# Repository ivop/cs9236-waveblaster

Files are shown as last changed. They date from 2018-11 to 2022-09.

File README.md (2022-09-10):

# cs9236-waveblaster

A shrunken version of this design has been sold as the CrystalBlaster C1 IVO edition :)
https://www.serdashop.com/CrystalBlasterC1

Now there's a shrunken SMD version called the CrystalBlaster C2
https://www.serdashop.com/CrystalBlaster-C2

Note that I am not in any way affiliated with the seller. My design is open source and the functionality has not changed. You can build it yourself or buy it :)

https://www.youtube.com/watch?v=O6CxHOC51vI

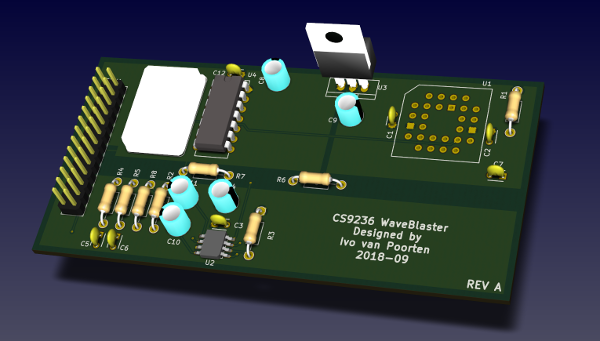
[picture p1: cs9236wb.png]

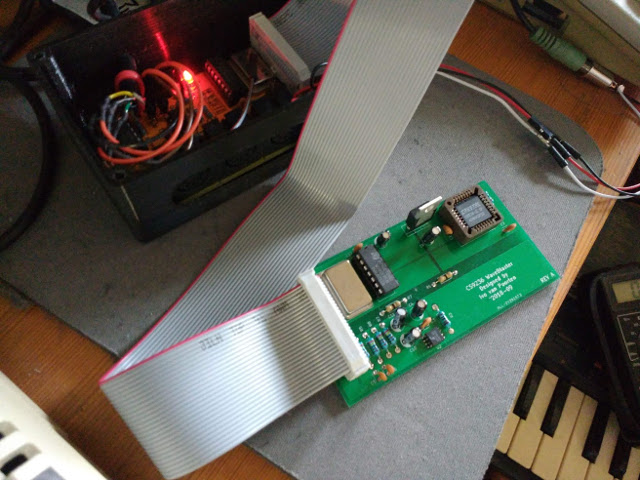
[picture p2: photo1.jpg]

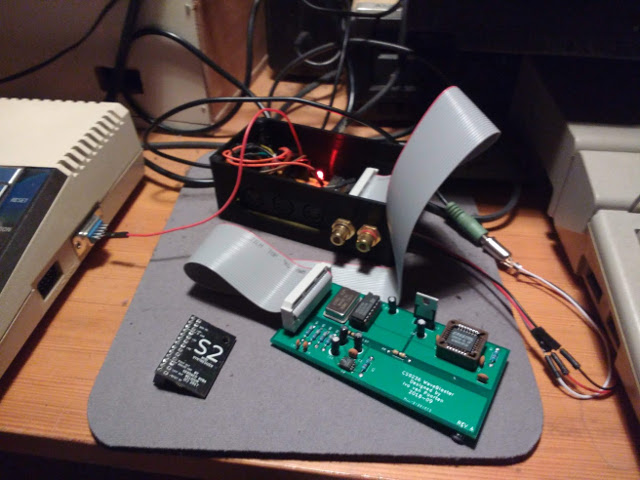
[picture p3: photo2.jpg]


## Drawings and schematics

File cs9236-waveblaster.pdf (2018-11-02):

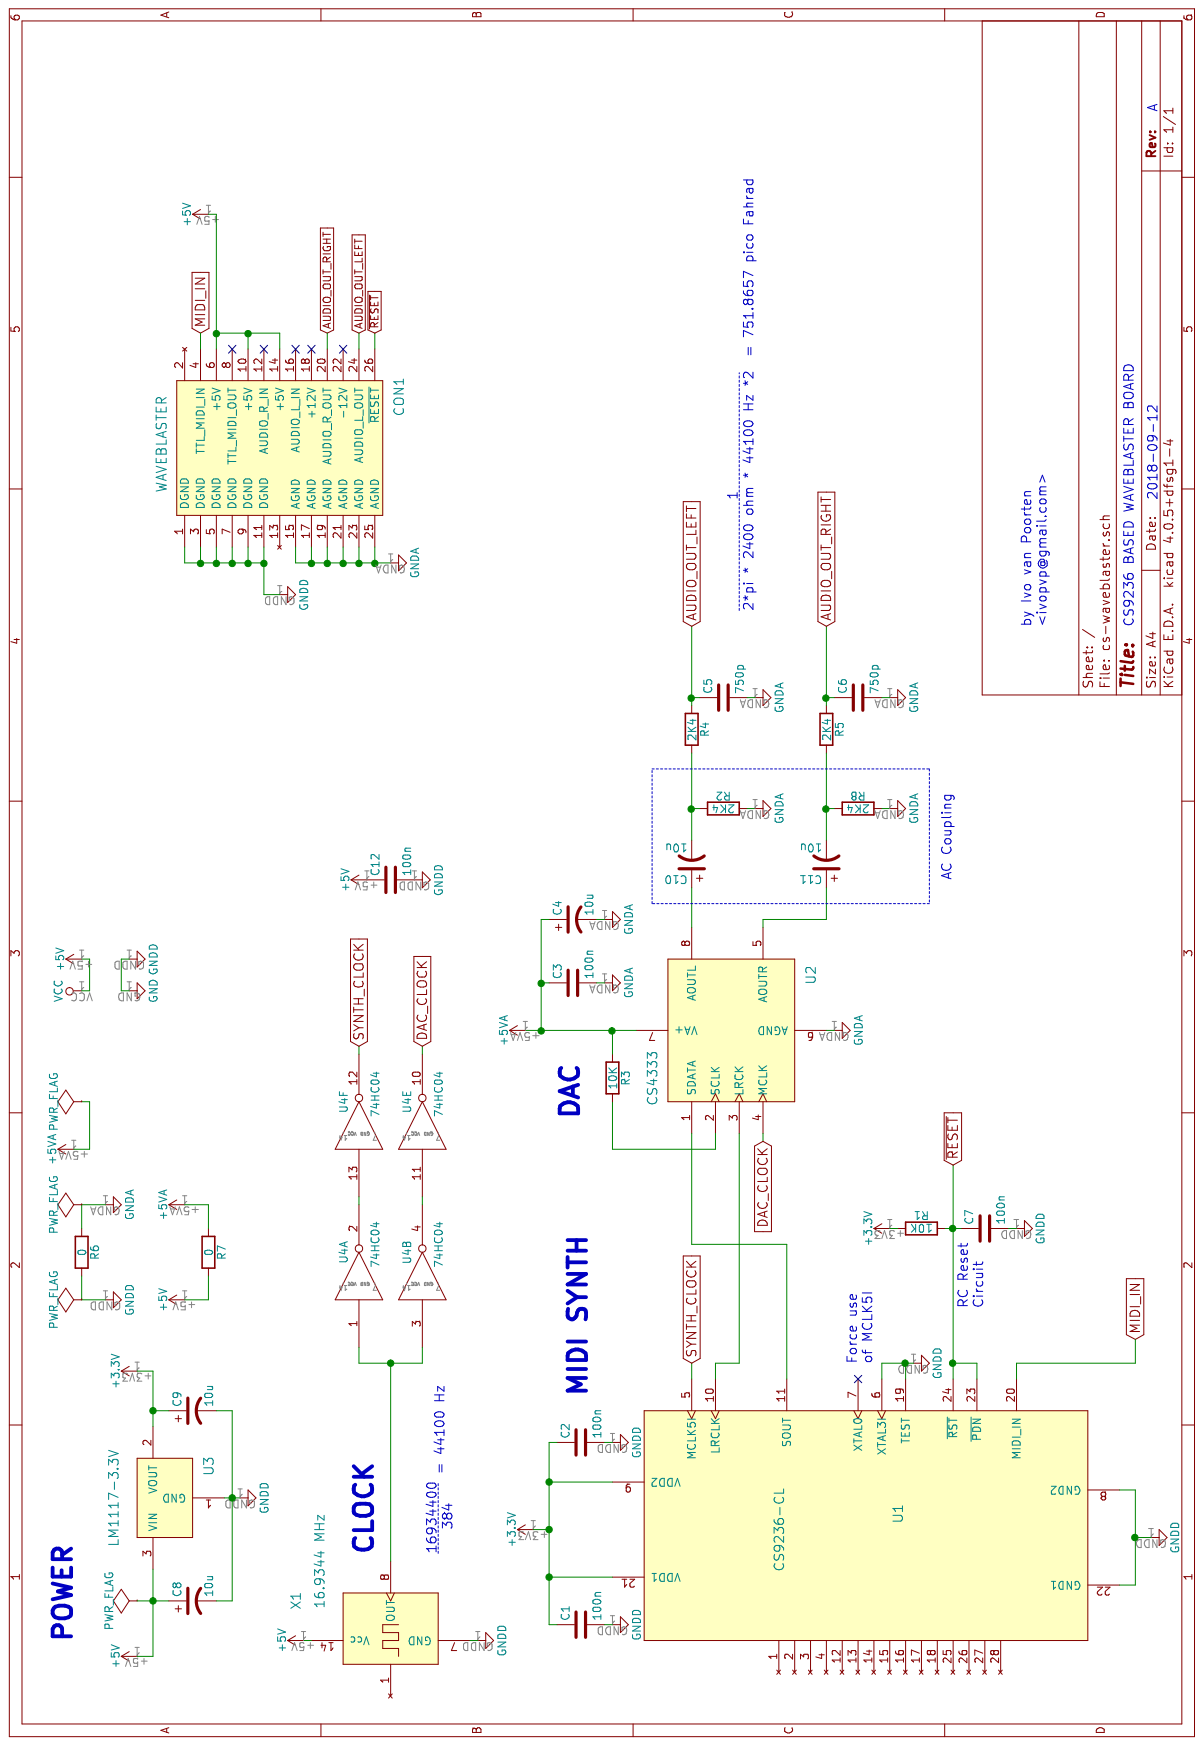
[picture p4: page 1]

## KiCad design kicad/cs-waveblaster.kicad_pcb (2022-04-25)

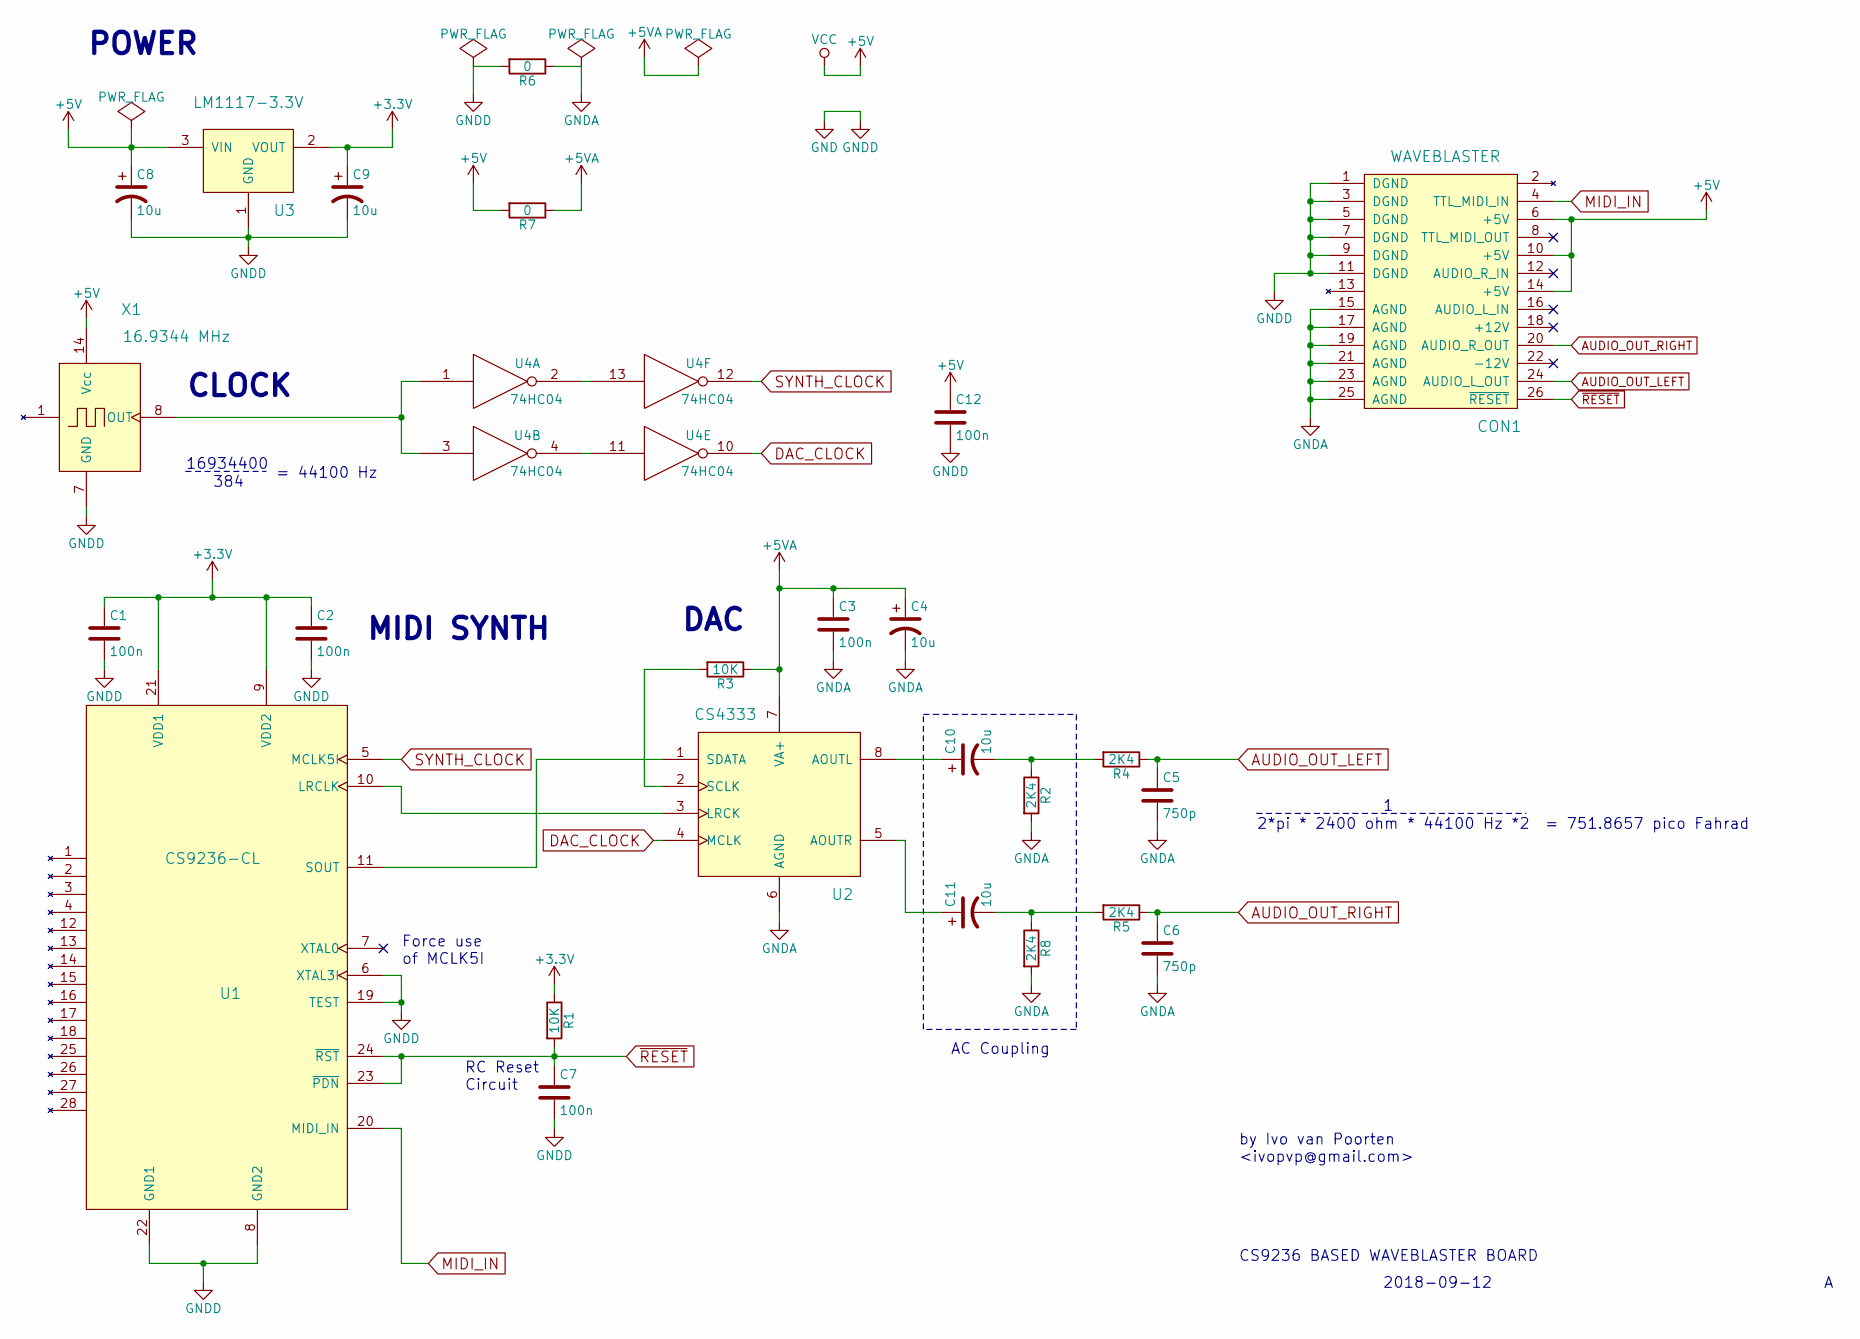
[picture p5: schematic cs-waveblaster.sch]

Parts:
C1, C2, C3, C7, C12: 100n; C_Disc_D3_P2.5
C4, C8, C9, C10, C11: 10u; C_Radial_D5_L6_P2.5
C5, C6: 750p; C_Disc_D3_P2.5
CON1: WAVEBLASTER; Pin_Header_Straight_2x13
R1, R3: 10K; Resistor_Horizontal_RM10mm
R2, R4, R5, R8: 2K4; Resistor_Horizontal_RM10mm
R6, R7: 0; Resistor_Horizontal_RM10mm
U1: CS9236-CL; PLCC28
U2: CS4333; SOIC-8-N
U3: LM1117-3.3V; TO-220_Neutral123_Vertical
U4: 74HC04; DIP-14_W7.62mm
X1: 16.9344 MHz; KXO-200_LargePads

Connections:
+3V3: C1.1, C2.1, C9.1, R1.1, U1.9 (VDD2), U1.21 (VDD1), U3.2 (VOUT)
+5V: C8.1, C12.1, CON1.6 (+5V), CON1.10 (+5V), CON1.14 (+5V), R7.2, U3.3 (VIN), U4.14 (VCC), X1.14 (Vcc)
+5VA: C3.1, C4.1, R3.1, R7.1, U2.7 (VA+)
AUDIO_OUT_LEFT: C5.1, CON1.24 (AUDIO_L_OUT), R4.1
AUDIO_OUT_RIGHT: C6.1, CON1.20 (AUDIO_R_OUT), R5.1
DAC_CLOCK: U2.4 (MCLK), U4.10
GND: C1.2, C2.2, C7.2, C8.2, C9.2, C12.2, CON1.1 (DGND), CON1.3 (DGND), CON1.5 (DGND), CON1.7 (DGND), CON1.9 (DGND), CON1.11 (DGND), R6.2, U1.6 (XTAL3I), U1.8 (GND2), U1.19 (TEST), U1.22 (GND1), U3.1 (GND), U4.7 (GND), X1.7 (GND)
GNDA: C3.2, C4.2, C5.2, C6.2, CON1.15 (AGND), CON1.17 (AGND), CON1.19 (AGND), CON1.21 (AGND), CON1.23 (AGND), CON1.25 (AGND), R2.2, R6.1, R8.2, U2.6 (AGND)
MIDI_IN: CON1.4 (TTL_MIDI_IN), U1.20 (MIDI_IN)
unnamed: C10.1, U2.8 (AOUTL)
unnamed: C10.2, R2.1, R4.2
unnamed: C11.1, U2.5 (AOUTR)
unnamed: C11.2, R5.2, R8.1
unnamed: R3.2, U2.2 (SCLK)
unnamed: U1.10 (LRCLK), U2.3 (LRCK)
unnamed: U1.11 (SOUT), U2.1 (SDATA)
unnamed: U4.1, U4.3, X1.8 (OUT)
unnamed: U4.4, U4.11
unnamed: U4.2, U4.13
SYNTH_CLOCK: U1.5 (MCLK5I), U4.12
~RESET: C7.1, CON1.26 (~RESET), R1.2, U1.23 (~PDN), U1.24 (~RST)

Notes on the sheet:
Force use of MCLK5I
RC Reset Circuit
= 751.8657 pico Fahrad
CS9236 BASED WAVEBLASTER BOARD
by Ivo van Poorten <ivopvp@gmail.com>
2018-09-12
2*pi * 2400 ohm * 44100 Hz *2
MIDI SYNTH
DAC
POWER
CLOCK
16934400
384
= 44100 Hz
AC Coupling

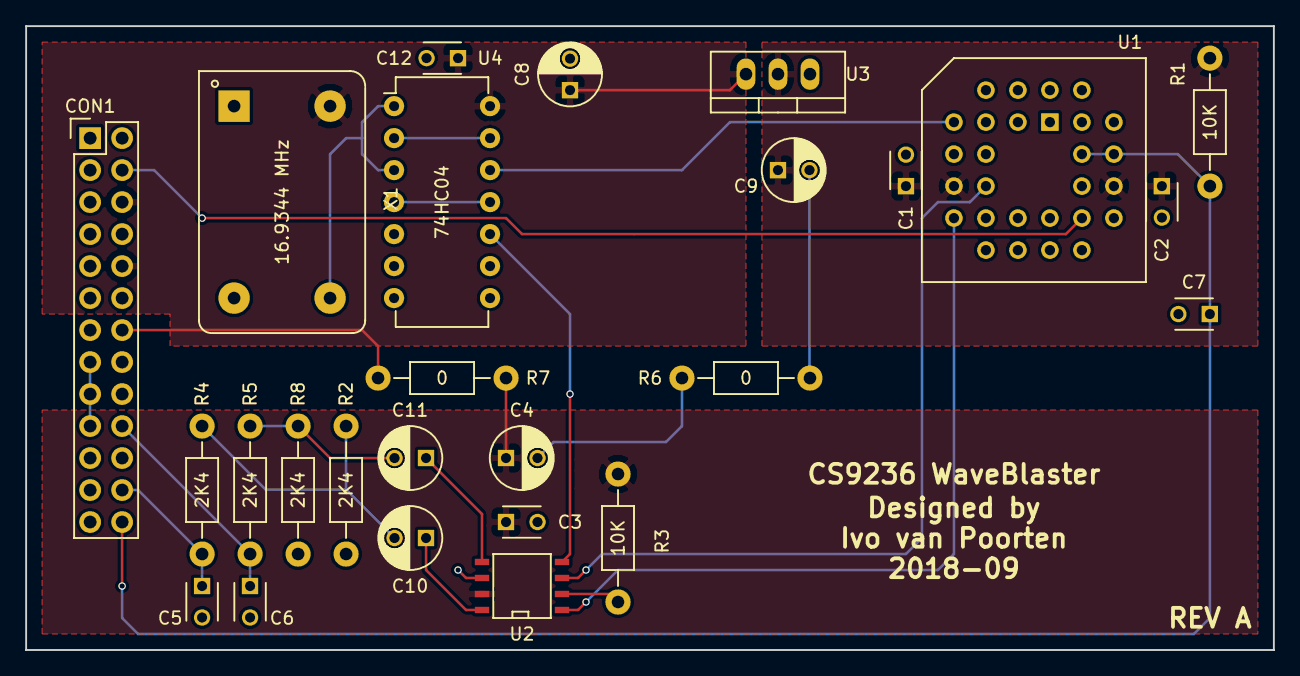
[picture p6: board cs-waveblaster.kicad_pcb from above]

Board: 2 copper layers, 99.1 x 49.5 mm, 26 parts (0 on the bottom side), 21 nets.

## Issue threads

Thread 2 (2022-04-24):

No PCB files

OctSL, 2022-04-24:
There is NO PCB files.
Could u add it?

ivop, 2022-04-24:
What do you mean by PCB files? The Gerber files for having a board produced are in the gerbers directory.

OctSL, 2022-04-25:
Not gerber.
I mean PCB files of KiCad(.kicad_pro)

ivop, 2022-04-25:
I see. Just committed the whole kicad project. HTH HAND :)

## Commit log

2018-11-02 revision a
    [cs-waveblaster-B.Cu.gbr, cs-waveblaster-B.Mask.gbr, cs-waveblaster-B.SilkS.gbr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]
2018-11-02 kicad rendering
2022-04-25 add kicad project
    [cs-waveblaster.kicad_pcb, cs-waveblaster.sch]
